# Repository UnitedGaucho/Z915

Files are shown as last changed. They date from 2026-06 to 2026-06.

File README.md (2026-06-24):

# Z915

An nRF52840 (MDBT50Q) wireless mechanical keyboard that fits in the chassis and recreates the functions of the Logitech G915. ZMK is used as the firmware.
G915 features to be recreated
  - Per-key RGB LED
  - Volume scroll wheel
  - Wireless (BLE)
  - Battery level reporting

Features to be added/upgraded
  - USB-C charging (G915 has micro-B USB)
  - Upgrade the feel of the rubber dome switches by using snap dome switches underneath the rubber
  - ZMK-included features

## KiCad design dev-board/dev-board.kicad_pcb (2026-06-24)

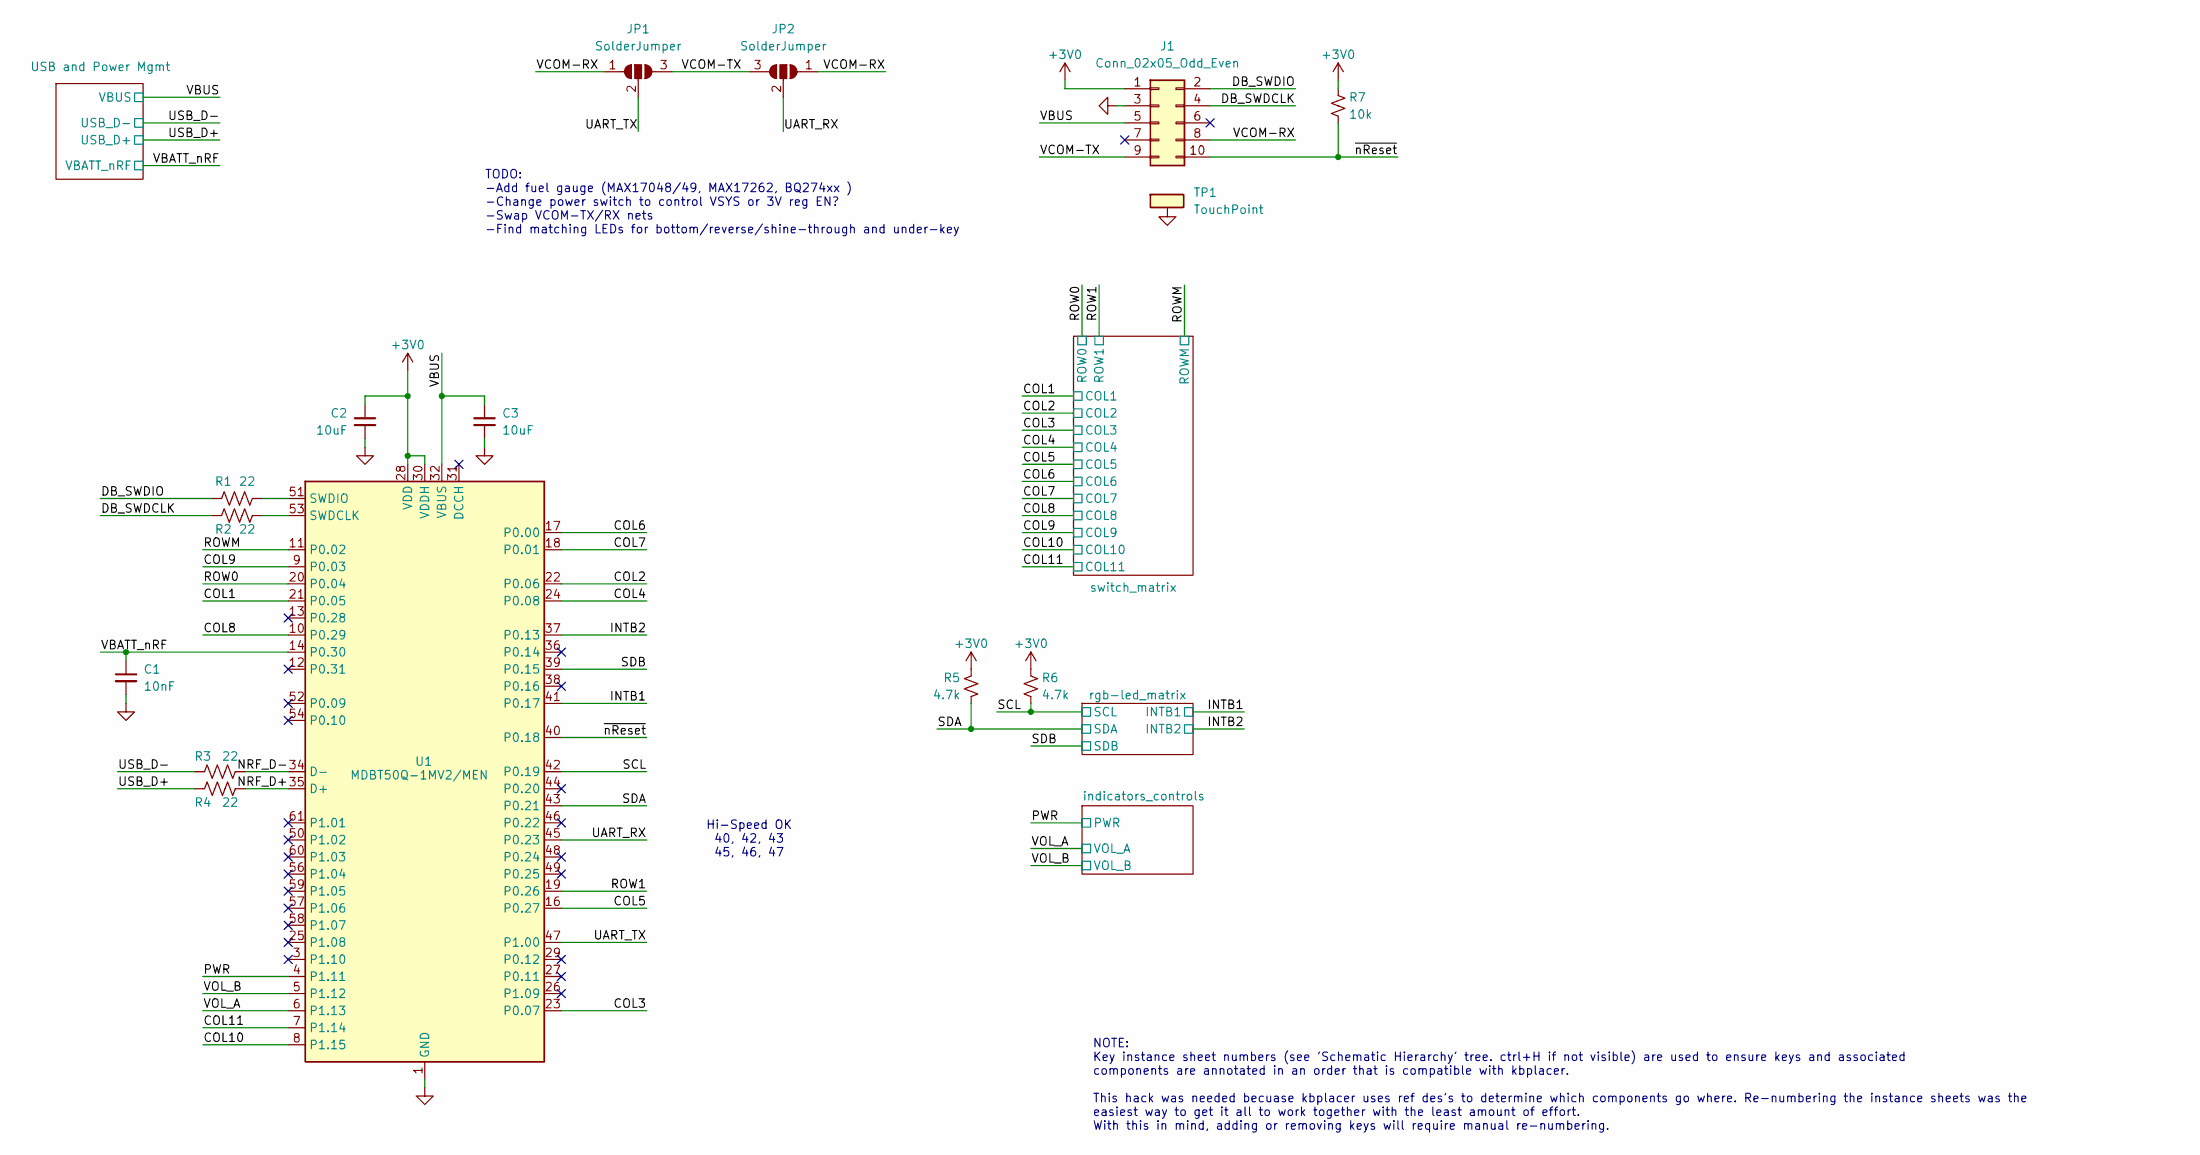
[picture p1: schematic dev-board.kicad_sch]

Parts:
C1: 10nF; C_0603_1608Metric
C2, C3: 10uF; C_1206_3216Metric
J1: Conn_02x05_Odd_Even; Tag-Connect_TC2050-IDC-FP_2x05_P1.27mm_Vertical
JP1, JP2: SolderJumper; SolderJumper-3_P1.3mm_Open_RoundedPad1.0x1.5mm
R1, R2, R3, R4: 22; R_0402_1005Metric
R5, R6: 4.7k; R_0402_1005Metric
R7: 10k; R_0402_1005Metric
TP1: TouchPoint; TestPoint_Pad_4.0x4.0mm
U1: MDBT50Q-1MV2/MEN; Raytac_MDBT50Q

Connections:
+3V0: C2.1, J1.1, R5.2, R6.2, R7.2, U1.28 (VDD), U1.30 (VDDH); also elsewhere on the board
/COL1: U1.21 (P0.05); also elsewhere on the board
/COL2: U1.22 (P0.06); also elsewhere on the board
/COL3: U1.23 (P0.07); also elsewhere on the board
/COL4: U1.24 (P0.08); also elsewhere on the board
/COL5: U1.16 (P0.27); also elsewhere on the board
/COL6: U1.17 (P0.00); also elsewhere on the board
/COL7: U1.18 (P0.01); also elsewhere on the board
/COL8: U1.10 (P0.29); also elsewhere on the board
/COL9: U1.9 (P0.03); also elsewhere on the board
/COL10: U1.8 (P1.15); also elsewhere on the board
/COL11: U1.7 (P1.14); also elsewhere on the board
/DB_SWDCLK: J1.4, R2.1
/DB_SWDIO: J1.2, R1.1
/INTB1: U1.41 (P0.17); also elsewhere on the board
/INTB2: U1.37 (P0.13); also elsewhere on the board
/NRF_D+: R4.2, U1.35 (D+)
/NRF_D-: R3.2, U1.34 (D-)
/PWR: U1.4 (P1.11); also elsewhere on the board
/ROW0: U1.20 (P0.04); also elsewhere on the board
/ROW1: U1.19 (P0.26); also elsewhere on the board
/ROWM: U1.11 (P0.02); also elsewhere on the board
/SCL: R6.1, U1.42 (P0.19); also elsewhere on the board
/SDA: R5.1, U1.43 (P0.21); also elsewhere on the board
/SDB: U1.39 (P0.15); also elsewhere on the board
/UART_RX: JP2.2 (C), U1.45 (P0.23)
/UART_TX: JP1.2 (C), U1.47 (P1.00)
/USB_D+: R4.1; also elsewhere on the board
/USB_D-: R3.1; also elsewhere on the board
/VBATT_nRF: C1.1, U1.14 (P0.30); also elsewhere on the board
/VBUS: C3.1, J1.5, U1.32 (VBUS); also elsewhere on the board
/VCOM-RX: J1.8, JP1.1 (A), JP2.1 (A)
/VCOM-TX: J1.9, JP1.3 (B), JP2.3 (B)
/VOL_A: U1.6 (P1.13); also elsewhere on the board
/VOL_B: U1.5 (P1.12); also elsewhere on the board
/~nReset: J1.10, R7.1, U1.40 (P0.18)
GND: C1.2, C2.2, C3.2, J1.3, TP1.1, U1.1 (GND), U1.2 (GND), U1.15 (GND), U1.33 (GND), U1.55 (GND); also elsewhere on the board
unnamed: R2.2, U1.53 (SWDCLK)
unnamed: R1.2, U1.51 (SWDIO)

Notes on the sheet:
NOTE: Key instance sheet numbers (see 'Schematic Hierarchy' tree. ctrl+H if not visible) are used to ensure keys and associated components are annotated in an order that is compatible with kbplacer. This hack was needed becuase kbplacer uses ref des's to determine which components go where. Re-numb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
Hi-Speed OK 40, 42, 43 45, 46, 47
TODO: -Add fuel gauge (MAX17048/49, MAX17262, BQ274xx ) -Change power switch to control VSYS or 3V reg EN? -Swap VCOM-TX/RX nets -Find matching LEDs for bottom/reverse/shine-through and under-key

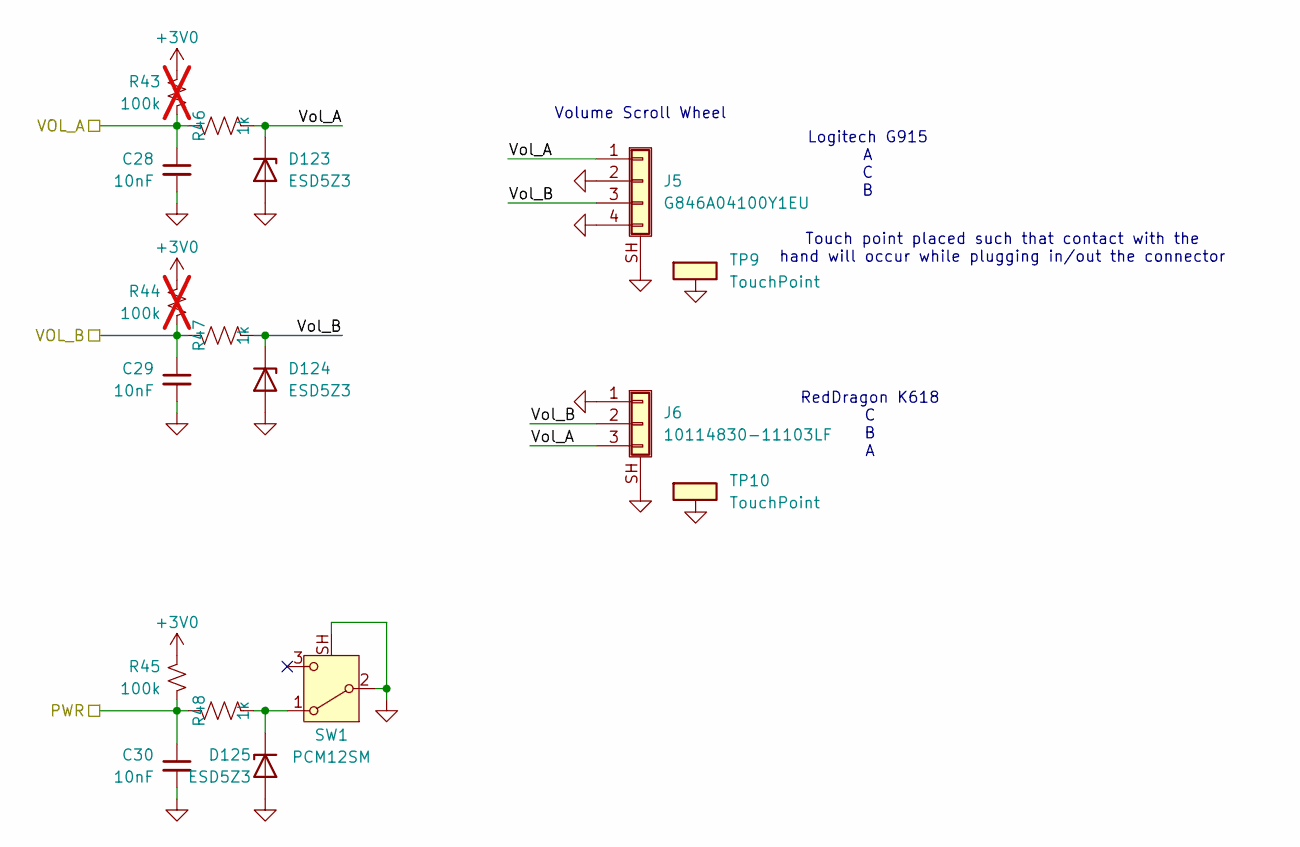
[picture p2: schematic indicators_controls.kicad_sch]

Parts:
C28, C29, C30: 10nF; C_0603_1608Metric
D123, D124, D125: ESD5Z3; D_SOD-523
J5: G846A04100Y1EU; AMPHENOL_G846A04100Y1EU
J6: 10114830-11103LF; AMPHENOL_10114830-11103LF
R43, R44: 100k; R_0402_1005Metric; not fitted
R45: 100k; R_0402_1005Metric
R46, R47, R48: 1k; R_0402_1005Metric
SW1: PCM12SM; SW_PCM12SMTR
TP9, TP10: TouchPoint; TestPoint_Pad_4.0x4.0mm

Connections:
+3V0: R43.2, R44.2, R45.2; also elsewhere on the board
/PWR: C30.1, R45.1, R48.1; also elsewhere on the board
/VOL_A: C28.1, R43.1, R46.1; also elsewhere on the board
/VOL_B: C29.1, R44.1, R47.1; also elsewhere on the board
/indicators_controls/Vol_A: D123.1 (K), J5.1, J6.3, R46.2
/indicators_controls/Vol_B: D124.1 (K), J5.3, J6.2, R47.2
GND: C28.2, C29.2, C30.2, D123.2 (A), D124.2 (A), D125.2 (A), J5.2, J5.4, J5.SH (Shield), J6.1, J6.SH (Shield), SW1.2 (B), SW1.SH, TP9.1, TP10.1; also elsewhere on the board
unnamed: D125.1 (K), R48.2, SW1.1 (A)

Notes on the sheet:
Logitech G915 A C B
Touch point placed such that contact with the hand will occur while plugging in/out the connector
RedDragon K618 C B A
Volume Scroll Wheel

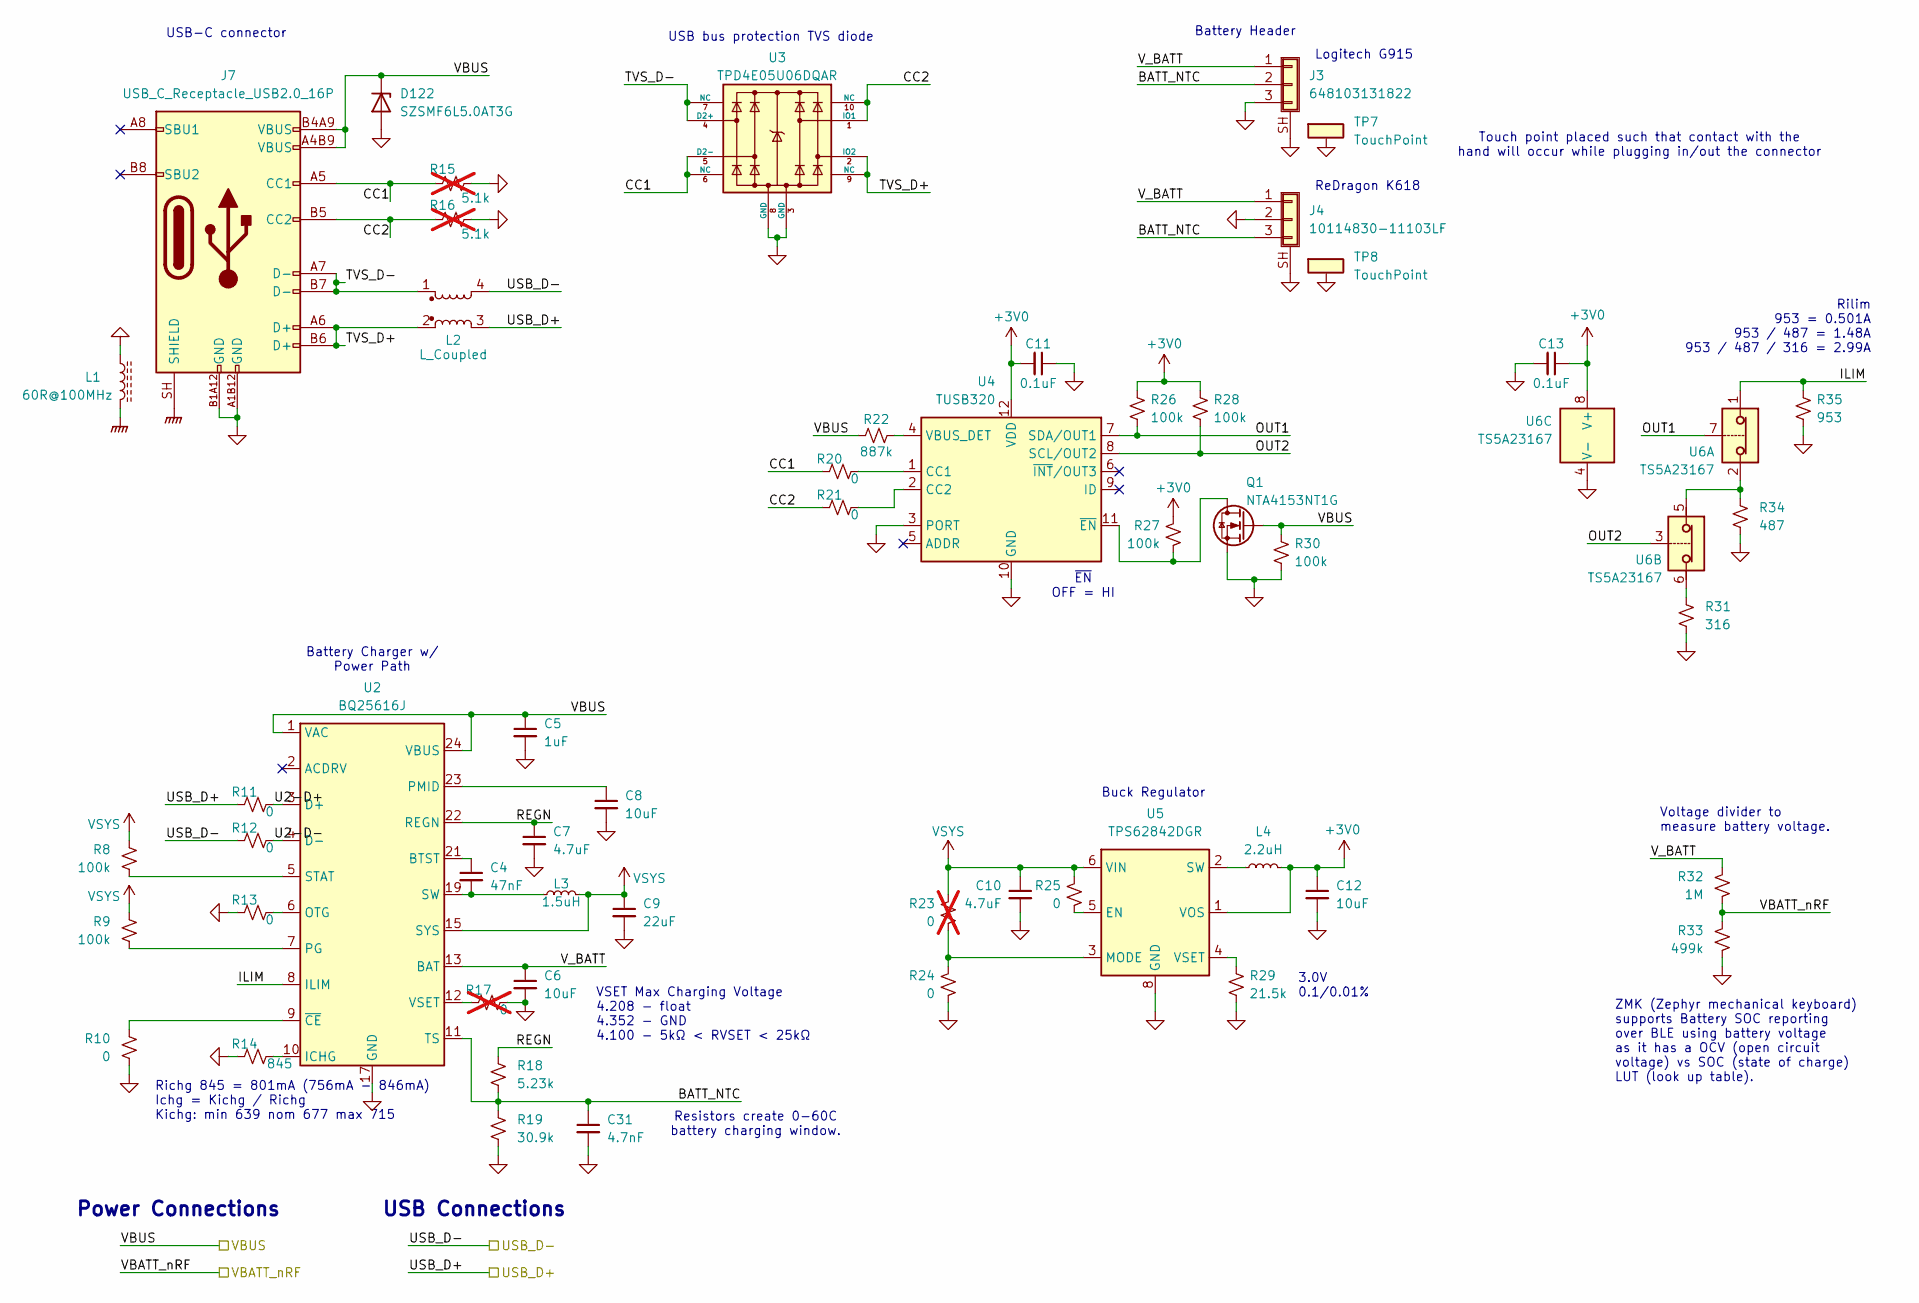
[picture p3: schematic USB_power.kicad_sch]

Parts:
C4: 47nF; C_0402_1005Metric
C5: 1uF; C_0603_1608Metric
C6, C8: 10uF; C_0805_2012Metric
C7: 4.7uF; C_0402_1005Metric
C9: 22uF; C_0805_2012Metric
C10: 4.7uF; C_0805_2012Metric
C11, C13: 0.1uF; C_0402_1005Metric
C12: 10uF; C_0402_1005Metric
C31: 4.7nF; C_0402_1005Metric
D122: SZSMF6L5.0AT3G; D_SOD-123F
J3: 648103131822
J4: 10114830-11103LF; AMPHENOL_10114830-11103LF
J7: USB_C_Receptacle_USB2.0_16P; AMPHENOL_12402012E212A
L1: 60R@100MHz; L_0603_1608Metric
L2: L_Coupled; FIL_ACM2012-900-2P-T001
L3: 1.5uH; L_1008_2520Metric
L4: 2.2uH; L_Murata_DFE201610P
Q1: NTA4153NT1G; SOT-416
R8, R9, R26, R27, R28, R30: 100k; R_0402_1005Metric
R10, R11, R12, R13, R20, R21, R24, R25: 0; R_0402_1005Metric
R14: 845; R_0402_1005Metric
R15, R16: 5.1k; R_0402_1005Metric; not fitted
R17, R23: 0; R_0402_1005Metric; not fitted
R18: 5.23k; R_0402_1005Metric
R19: 30.9k; R_0402_1005Metric
R22: 887k; R_0402_1005Metric
R29: 21.5k; R_0402_1005Metric
R31: 316; R_0402_1005Metric
R32: 1M; R_0402_1005Metric
R33: 499k; R_0402_1005Metric
R34: 487; R_0402_1005Metric
R35: 953; R_0402_1005Metric
TP7, TP8: TouchPoint; TestPoint_Pad_4.0x4.0mm
U2: BQ25616J; Texas_RTW_WQFN-24-1EP_4x4mm_P0.5mm_EP2.7x2.7mm_ThermalVias
U3: TPD4E05U06DQAR; USON-10
U4: TUSB320; Texas_X2QFN-12_1.6x1.6mm_P0.4mm
U5: TPS62842DGR; HVSSOP-8-1EP_3x3mm_P0.65mm_EP1.57x1.89mm
U6: TS5A23167; VSSOP-8_2.3x2mm_P0.5mm

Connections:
+3V0: C11.2, C12.1, C13.1, L4.2, R26.2, R27.2, R28.2, U4.12 (VDD), U5.1 (VOS), U6.8 (V+); also elsewhere on the board
/USB and Power Mgmt/BATT_NTC: C31.1, J3.2, J4.3, R18.1, R19.2, U2.11 (TS)
/USB and Power Mgmt/CC1: J7.A5 (CC1), R15.2, R20.2, U3.5 (D2-), U3.6 (NC)
/USB and Power Mgmt/CC2: J7.B5 (CC2), R16.2, R21.2, U3.1 (IO1), U3.10 (NC)
/USB and Power Mgmt/ILIM: R35.2, U2.8 (ILIM), U6.1
/USB and Power Mgmt/OUT1: R26.1, U4.7 (SDA/OUT1), U6.7
/USB and Power Mgmt/OUT2: R28.1, U4.8 (SCL/OUT2), U6.3
/USB and Power Mgmt/REGN: C7.1, R18.2, U2.22 (REGN)
/USB and Power Mgmt/TVS_D+: J7.A6 (D+), J7.B6 (D+), L2.2, U3.2 (IO2), U3.9 (NC)
/USB and Power Mgmt/TVS_D-: J7.A7 (D-), J7.B7 (D-), L2.1, U3.4 (D2+), U3.7 (NC)
/USB and Power Mgmt/U2-D+: R11.1, U2.3 (D+)
/USB and Power Mgmt/U2-D-: R12.1, U2.4 (D-)
/USB_D+: L2.3, R11.2; also elsewhere on the board
/USB_D-: L2.4, R12.2; also elsewhere on the board
/VBATT_nRF: R32.1, R33.2; also elsewhere on the board
/VBUS: C5.1, D122.1 (K), J7.A4B9 (VBUS), J7.B4A9 (VBUS), Q1.G, R22.2, R30.2, U2.1 (VAC), U2.24 (VBUS); also elsewhere on the board
BAT: C6.1, J3.1, J4.1, R32.2, U2.13 (BAT), U2.14 (BAT)
GND: C5.2, C6.2, C7.2, C8.2, C9.2, C10.2, C11.1, C12.2, C13.2, C31.2, D122.2 (A), J3.3, J3.SH (Shield), J4.2, J4.SH (Shield), J7.A1B12 (GND), J7.B1A12 (GND), L1.1, Q1.S, R10.2, R13.2, R14.2, R15.1, R16.1, R17.1, R19.1, R24.1, R29.1, R30.1, R31.1, R33.1, R34.1, R35.1, TP7.1, TP8.1, U2.17 (GND), U2.18 (GND), U2.25 (GND), U3.3 (GND), U3.8 (GND), U4.3 (PORT), U4.10 (GND), U5.8 (GND), U5.9 (EP), U6.4 (V-); also elsewhere on the board
GNDPWR: J7.SH (SHIELD), L1.2
unnamed: C4.2, L3.1, U2.19 (SW), U2.20 (SW)
unnamed: R31.2, U6.6
unnamed: R34.2, U6.2, U6.5
unnamed: C4.1, U2.21 (BTST)
unnamed: R14.1, U2.10 (ICHG)
unnamed: R13.1, U2.6 (OTG)
unnamed: R9.2, U2.7 (PG)
unnamed: C8.1, U2.23 (PMID)
unnamed: R8.2, U2.5 (STAT)
unnamed: R17.2, U2.12 (VSET)
unnamed: R10.1, U2.9 (~CE)
unnamed: R20.1, U4.1 (CC1)
unnamed: R21.1, U4.2 (CC2)
unnamed: R22.1, U4.4 (VBUS_DET)
unnamed: Q1.D, R27.1, U4.11 (~EN)
unnamed: R25.1, U5.5 (EN)
unnamed: R23.1, R24.2, U5.3 (MODE)
unnamed: L4.1, U5.2 (SW)
unnamed: R29.2, U5.4 (VSET)
VSYS: C9.1, C10.1, L3.2, R8.1, R9.1, R23.2, R25.2, U2.15 (SYS), U2.16 (SYS), U5.6 (VIN); also elsewhere on the board

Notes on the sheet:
ReDragon K618
Resistors create 0-60C battery charging window.
Voltage divider to measure battery voltage.
Touch point placed such that contact with the hand will occur while plugging in/out the connector
Battery Charger w/ Power Path
USB bus protection TVS diode
Richg 845 = 801mA (756mA - 846mA) Ichg = Kichg / Richg Kichg: min 639 nom 677 max 715
3.0V 0.1/0.01%
USB Connections
Buck Regulator
USB-C connector
Logitech G915
ZMK (Zephyr mechanical keyboard) supports Battery SOC reporting over BLE using battery voltage as it has a OCV (open circuit voltage) vs SOC (state of charge) LUT (look up table).
Rilim 953 = 0.501A 953 / 487 = 1.48A 953 / 487 / 316 = 2.99A
VSET Max Charging Voltage 4.208 - float 4.352 - GND 4.100 - 5kΩ < RVSET < 25kΩ
Battery Header
Power Connections
~{EN} OFF = HI

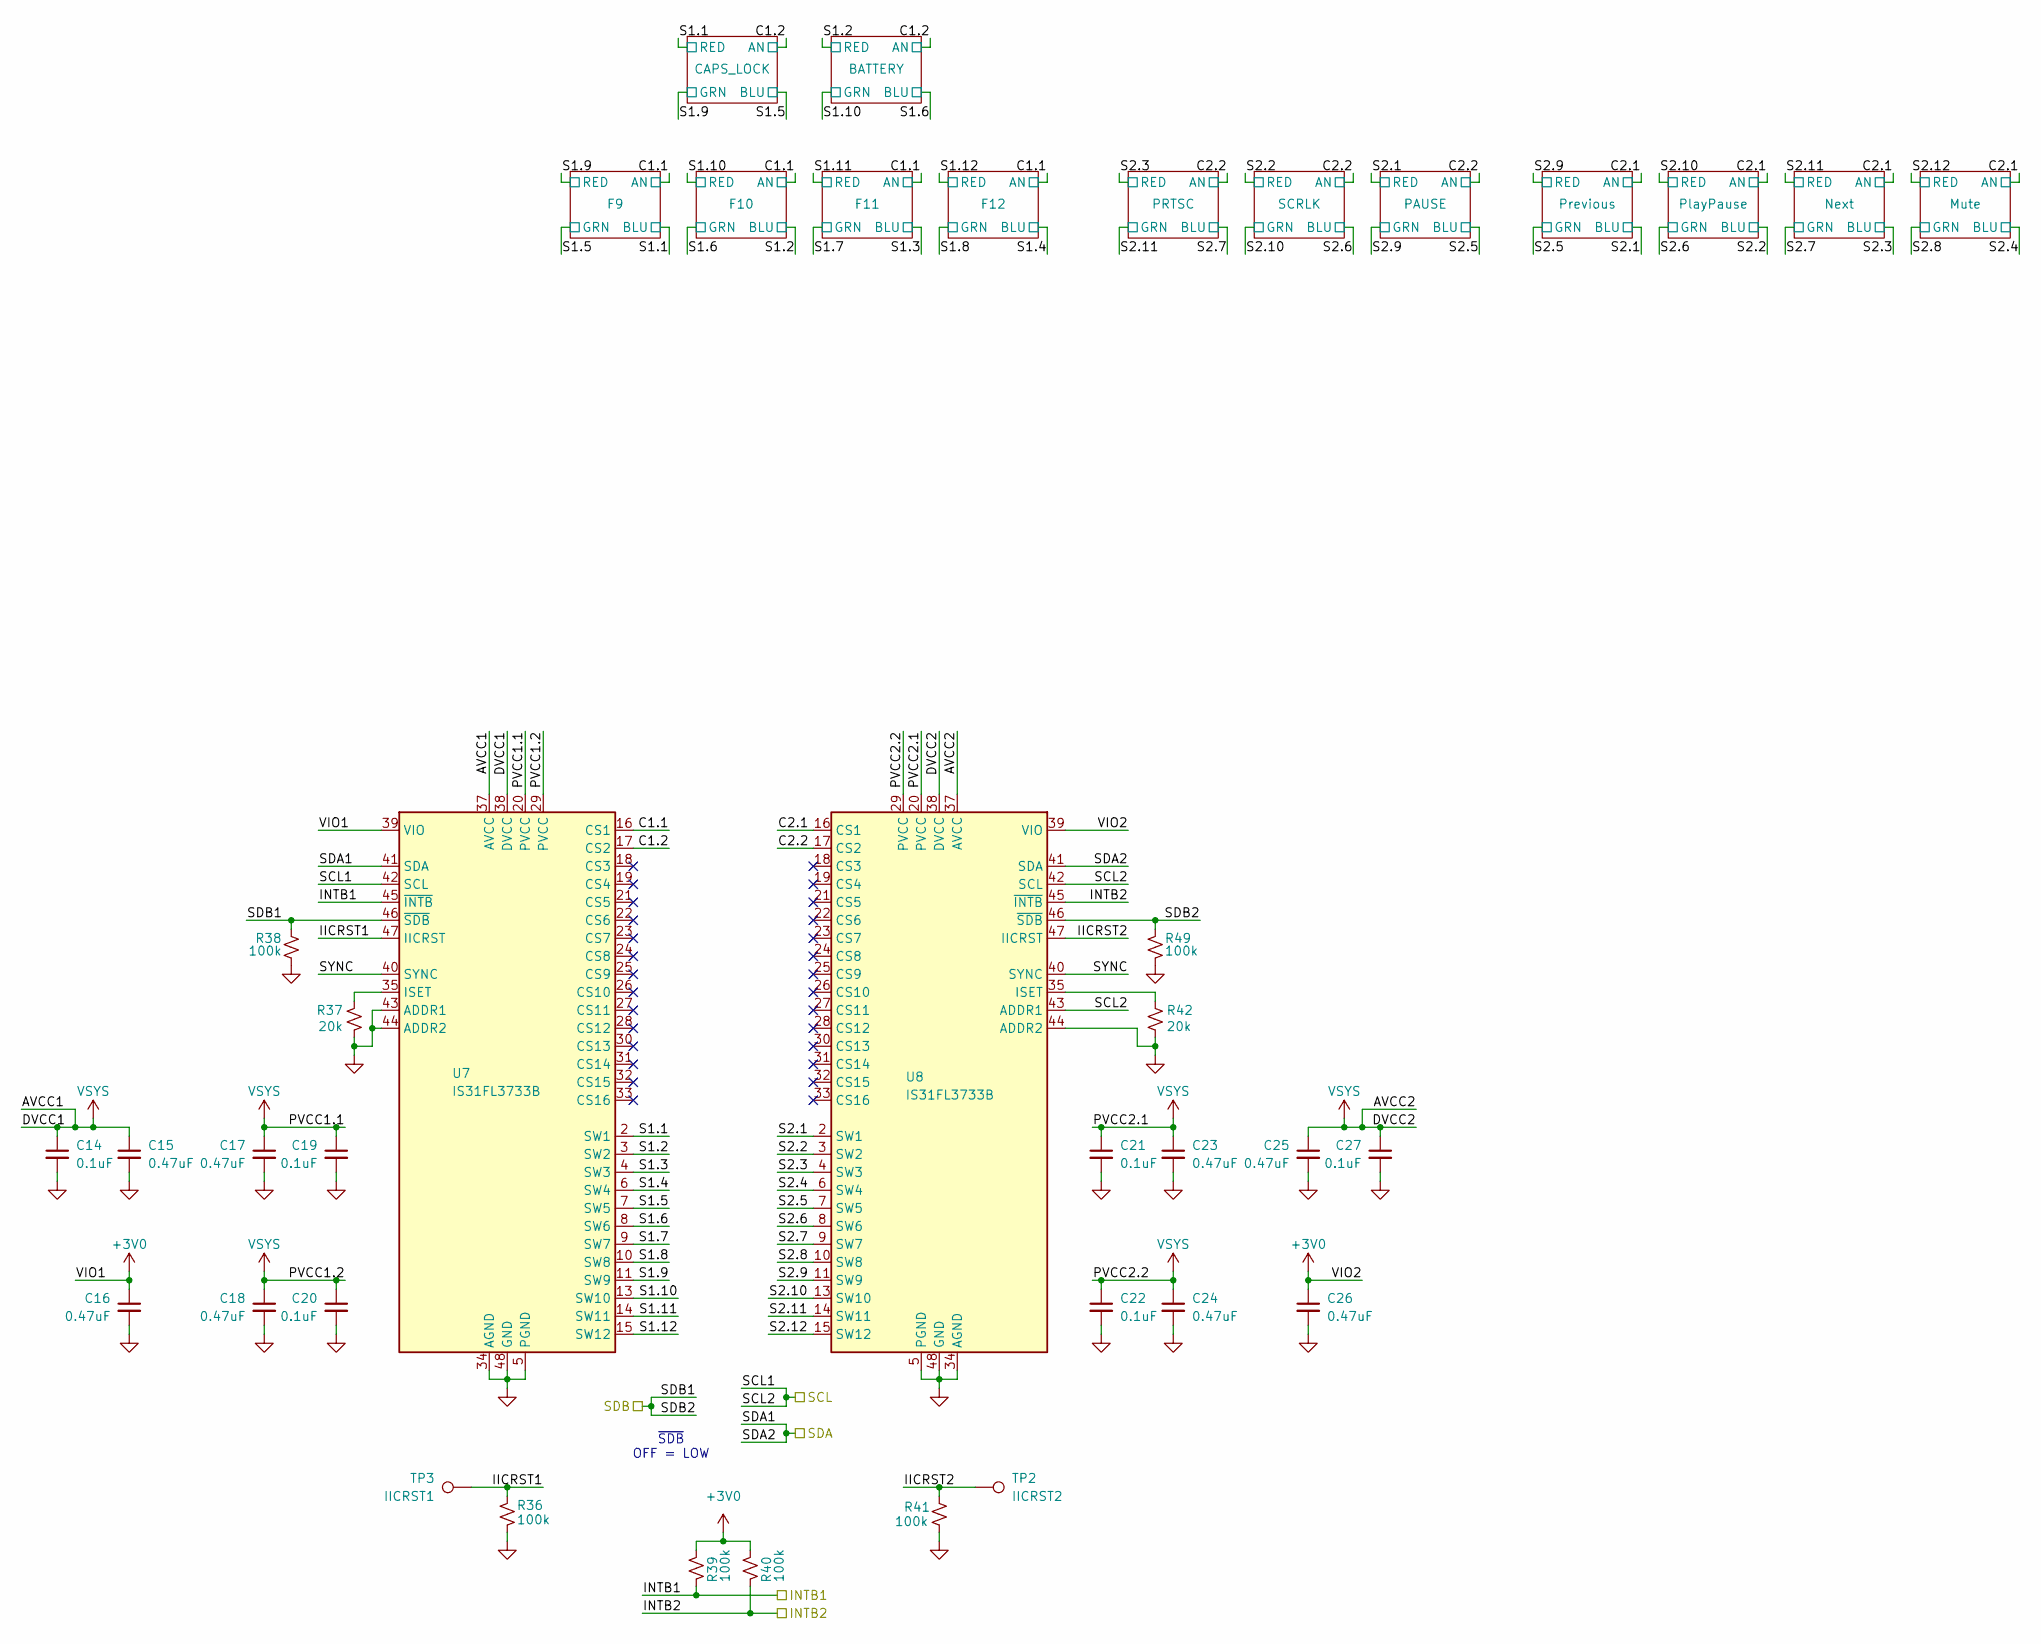
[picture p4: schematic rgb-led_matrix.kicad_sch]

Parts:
C14, C19, C20, C21, C22, C27: 0.1uF; C_0402_1005Metric
C15, C16, C17, C18, C23, C24, C25, C26: 0.47uF; C_0402_1005Metric
R36, R38, R39, R40, R41, R49: 100k; R_0402_1005Metric
R37, R42: 20k; R_0402_1005Metric
TP2: IICRST2; TestPoint_Pad_D1.0mm
TP3: IICRST1; TestPoint_Pad_D1.0mm
U7, U8: IS31FL3733B; TQFP-48-1EP_7x7mm_P0.5mm_EP5x5mm

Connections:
+3V0: C16.1, C26.1, R39.2, R40.2, U7.39 (VIO), U8.39 (VIO); also elsewhere on the board
/INTB1: R39.1, U7.45 (~INTB); also elsewhere on the board
/INTB2: R40.1, U8.45 (~INTB); also elsewhere on the board
/SCL: U7.42 (SCL), U8.42 (SCL), U8.43 (ADDR1); also elsewhere on the board
/SDA: U7.41 (SDA), U8.41 (SDA); also elsewhere on the board
/SDB: R38.2, R49.2, U7.46 (~SDB), U8.46 (~SDB); also elsewhere on the board
/rgb-led_matrix/C1.1: U7.16 (CS1); also elsewhere on the board
/rgb-led_matrix/C1.2: U7.17 (CS2); also elsewhere on the board
/rgb-led_matrix/C2.1: U8.16 (CS1); also elsewhere on the board
/rgb-led_matrix/C2.2: U8.17 (CS2); also elsewhere on the board
/rgb-led_matrix/IICRST1: R36.2, TP3.1 (1_1), U7.47 (IICRST)
/rgb-led_matrix/IICRST2: R41.1, TP2.1 (1_1), U8.47 (IICRST)
/rgb-led_matrix/S1.1: U7.2 (SW1); also elsewhere on the board
/rgb-led_matrix/S1.2: U7.3 (SW2); also elsewhere on the board
/rgb-led_matrix/S1.3: U7.4 (SW3); also elsewhere on the board
/rgb-led_matrix/S1.4: U7.6 (SW4); also elsewhere on the board
/rgb-led_matrix/S1.5: U7.7 (SW5); also elsewhere on the board
/rgb-led_matrix/S1.6: U7.8 (SW6); also elsewhere on the board
/rgb-led_matrix/S1.7: U7.9 (SW7); also elsewhere on the board
/rgb-led_matrix/S1.8: U7.10 (SW8); also elsewhere on the board
/rgb-led_matrix/S1.9: U7.11 (SW9); also elsewhere on the board
/rgb-led_matrix/S1.10: U7.13 (SW10); also elsewhere on the board
/rgb-led_matrix/S1.11: U7.14 (SW11); also elsewhere on the board
/rgb-led_matrix/S1.12: U7.15 (SW12); also elsewhere on the board
/rgb-led_matrix/S2.1: U8.2 (SW1); also elsewhere on the board
/rgb-led_matrix/S2.2: U8.3 (SW2); also elsewhere on the board
/rgb-led_matrix/S2.3: U8.4 (SW3); also elsewhere on the board
/rgb-led_matrix/S2.4: U8.6 (SW4); also elsewhere on the board
/rgb-led_matrix/S2.5: U8.7 (SW5); also elsewhere on the board
/rgb-led_matrix/S2.6: U8.8 (SW6); also elsewhere on the board
/rgb-led_matrix/S2.7: U8.9 (SW7); also elsewhere on the board
/rgb-led_matrix/S2.8: U8.10 (SW8); also elsewhere on the board
/rgb-led_matrix/S2.9: U8.11 (SW9); also elsewhere on the board
/rgb-led_matrix/S2.10: U8.13 (SW10); also elsewhere on the board
/rgb-led_matrix/S2.11: U8.14 (SW11); also elsewhere on the board
/rgb-led_matrix/S2.12: U8.15 (SW12); also elsewhere on the board
/rgb-led_matrix/SYNC: U7.40 (SYNC), U8.40 (SYNC)
GND: C14.2, C15.2, C16.2, C17.2, C18.2, C19.2, C20.2, C21.2, C22.2, C23.2, C24.2, C25.2, C26.2, C27.2, R36.1, R37.2, R38.1, R41.2, R42.2, R49.1, U7.5 (PGND), U7.12 (PGND), U7.34 (AGND), U7.43 (ADDR1), U7.44 (ADDR2), U7.48 (GND), U7.49 (GND), U8.5 (PGND), U8.12 (PGND), U8.34 (AGND), U8.44 (ADDR2), U8.48 (GND), U8.49 (GND); also elsewhere on the board
unnamed: R37.1, U7.35 (ISET)
unnamed: R42.1, U8.35 (ISET)
VSYS: C14.1, C15.1, C17.1, C18.1, C19.1, C20.1, C21.1, C22.1, C23.1, C24.1, C25.1, C27.1, U7.20 (PVCC), U7.29 (PVCC), U7.37 (AVCC), U7.38 (DVCC), U8.20 (PVCC), U8.29 (PVCC), U8.37 (AVCC), U8.38 (DVCC); also elsewhere on the board

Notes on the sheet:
~{SDB} OFF = LOW

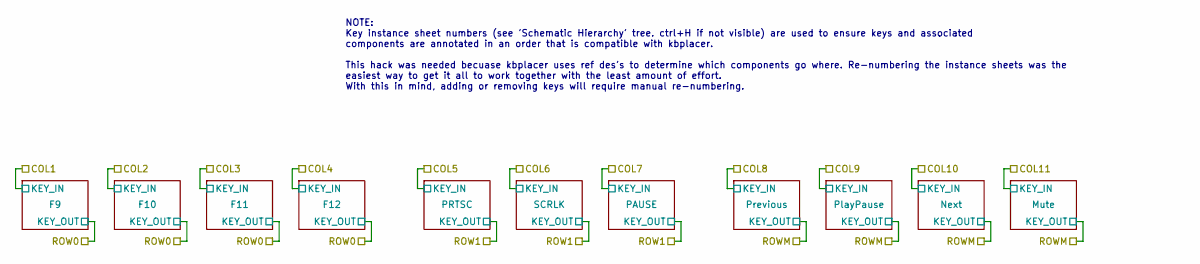
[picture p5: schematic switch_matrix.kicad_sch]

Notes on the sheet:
NOTE: Key instance sheet numbers (see 'Schematic Hierarchy' tree. ctrl+H if not visible) are used to ensure keys and associated components are annotated in an order that is compatible with kbplacer. This hack was needed becuase kbplacer uses ref des's to determine which components go where. Re-numb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

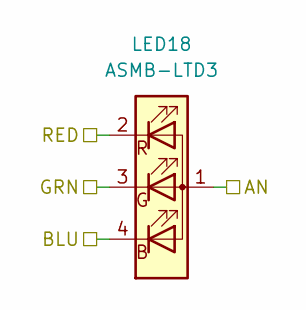
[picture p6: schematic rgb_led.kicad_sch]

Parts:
LED18: ASMB-LTD3; LED_ASMB-LTD3

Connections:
/rgb-led_matrix/C1.1: LED18.1 (A); also elsewhere on the board
/rgb-led_matrix/S1.1: LED18.4 (BK); also elsewhere on the board
/rgb-led_matrix/S1.5: LED18.3 (GK); also elsewhere on the board
/rgb-led_matrix/S1.9: LED18.2 (RK); also elsewhere on the board

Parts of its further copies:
LED19, LED20, LED21, LED22, LED23, LED24, LED122, LED123: ASMB-LTD3; LED_ASMB-LTD3

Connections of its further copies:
/rgb-led_matrix/C1.1: LED19.1 (A), LED20.1 (A), LED21.1 (A); also elsewhere on the board
/rgb-led_matrix/C1.2: LED122.1 (A), LED123.1 (A); also elsewhere on the board
/rgb-led_matrix/C2.2: LED22.1 (A), LED23.1 (A), LED24.1 (A); also elsewhere on the board
/rgb-led_matrix/S1.1: LED122.2 (RK); also elsewhere on the board
/rgb-led_matrix/S1.2: LED19.4 (BK), LED123.2 (RK); also elsewhere on the board
/rgb-led_matrix/S1.3: LED20.4 (BK); also elsewhere on the board
/rgb-led_matrix/S1.4: LED21.4 (BK); also elsewhere on the board
/rgb-led_matrix/S1.5: LED122.4 (BK); also elsewhere on the board
/rgb-led_matrix/S1.6: LED19.3 (GK), LED123.4 (BK); also elsewhere on the board
/rgb-led_matrix/S1.7: LED20.3 (GK); also elsewhere on the board
/rgb-led_matrix/S1.8: LED21.3 (GK); also elsewhere on the board
/rgb-led_matrix/S1.9: LED122.3 (GK); also elsewhere on the board
/rgb-led_matrix/S1.10: LED19.2 (RK), LED123.3 (GK); also elsewhere on the board
/rgb-led_matrix/S1.11: LED20.2 (RK); also elsewhere on the board
/rgb-led_matrix/S1.12: LED21.2 (RK); also elsewhere on the board
/rgb-led_matrix/S2.1: LED24.2 (RK); also elsewhere on the board
/rgb-led_matrix/S2.2: LED23.2 (RK); also elsewhere on the board
/rgb-led_matrix/S2.3: LED22.2 (RK); also elsewhere on the board
/rgb-led_matrix/S2.5: LED24.4 (BK); also elsewhere on the board
/rgb-led_matrix/S2.6: LED23.4 (BK); also elsewhere on the board
/rgb-led_matrix/S2.7: LED22.4 (BK); also elsewhere on the board
/rgb-led_matrix/S2.9: LED24.3 (GK); also elsewhere on the board
/rgb-led_matrix/S2.10: LED23.3 (GK); also elsewhere on the board
/rgb-led_matrix/S2.11: LED22.3 (GK); also elsewhere on the board

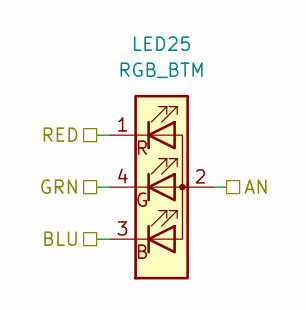
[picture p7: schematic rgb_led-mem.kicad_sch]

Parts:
LED25: RGB_BTM; LED_XZMDKCBDDG45S-9

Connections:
/rgb-led_matrix/C2.1: LED25.2 (A); also elsewhere on the board
/rgb-led_matrix/S2.1: LED25.3 (BK); also elsewhere on the board
/rgb-led_matrix/S2.5: LED25.4 (GK); also elsewhere on the board
/rgb-led_matrix/S2.9: LED25.1 (RK); also elsewhere on the board

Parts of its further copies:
LED26: RGB_BTM; LED_XZMDKCBDDG45S-9

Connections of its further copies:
/rgb-led_matrix/C2.1: LED26.2 (A); also elsewhere on the board
/rgb-led_matrix/S2.2: LED26.3 (BK); also elsewhere on the board
/rgb-led_matrix/S2.6: LED26.4 (GK); also elsewhere on the board
/rgb-led_matrix/S2.10: LED26.1 (RK); also elsewhere on the board

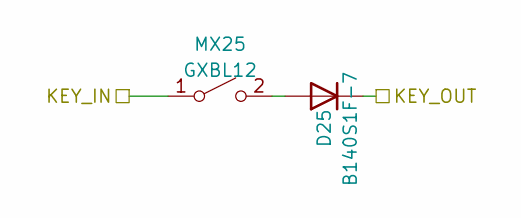
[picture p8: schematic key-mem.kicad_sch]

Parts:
D25: B140S1F-7; D_SOD-123F
MX25: GXBL12; SW_GXBL12450

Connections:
/COL8: MX25.1 (A); also elsewhere on the board
/ROWM: D25.1 (K); also elsewhere on the board
unnamed: D25.2 (A), MX25.2 (B)

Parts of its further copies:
D26, D27, D28: B140S1F-7; D_SOD-123F
MX26, MX27, MX28: GXBL12; SW_GXBL12450

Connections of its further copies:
/COL9: MX26.1 (A); also elsewhere on the board
/COL10: MX27.1 (A); also elsewhere on the board
/COL11: MX28.1 (A); also elsewhere on the board
/ROWM: D26.1 (K), D27.1 (K), D28.1 (K); also elsewhere on the board
unnamed: D26.2 (A), MX26.2 (B)
unnamed: D27.2 (A), MX27.2 (B)
unnamed: D28.2 (A), MX28.2 (B)

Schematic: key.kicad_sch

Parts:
D18: B140S1F-7; D_SOD-123F
MX18: 1.00u; SW_Kailh_Choc_V1_THT

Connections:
/COL1: MX18.2 (B); also elsewhere on the board
/ROW0: D18.1 (K); also elsewhere on the board
unnamed: D18.2 (A), MX18.1 (A)

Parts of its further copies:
D19, D20, D21, D22, D23, D24: B140S1F-7; D_SOD-123F
MX19, MX20, MX21, MX22, MX23, MX24: 1.00u; SW_Kailh_Choc_V1_THT

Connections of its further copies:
/COL2: MX19.2 (B); also elsewhere on the board
/COL3: MX20.2 (B); also elsewhere on the board
/COL4: MX21.2 (B); also elsewhere on the board
/COL5: MX22.2 (B); also elsewhere on the board
/COL6: MX23.2 (B); also elsewhere on the board
/COL7: MX24.2 (B); also elsewhere on the board
/ROW0: D19.1 (K), D20.1 (K), D21.1 (K); also elsewhere on the board
/ROW1: D22.1 (K), D23.1 (K), D24.1 (K); also elsewhere on the board
unnamed: D19.2 (A), MX19.1 (A)
unnamed: D20.2 (A), MX20.1 (A)
unnamed: D21.2 (A), MX21.1 (A)
unnamed: D22.2 (A), MX22.1 (A)
unnamed: D23.2 (A), MX23.1 (A)
unnamed: D24.2 (A), MX24.1 (A)

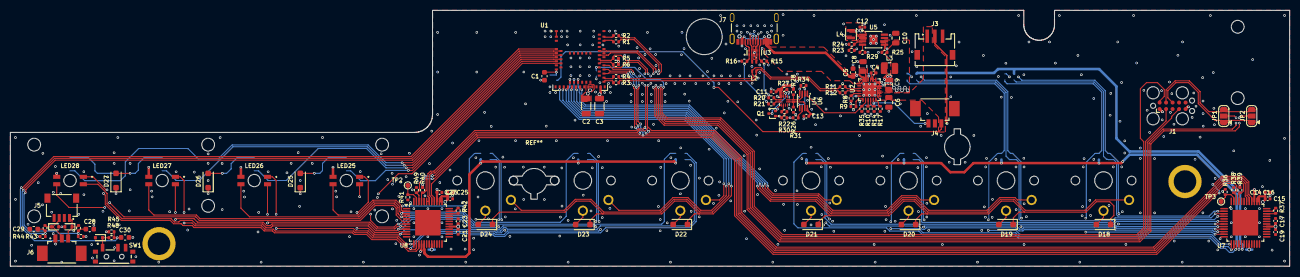
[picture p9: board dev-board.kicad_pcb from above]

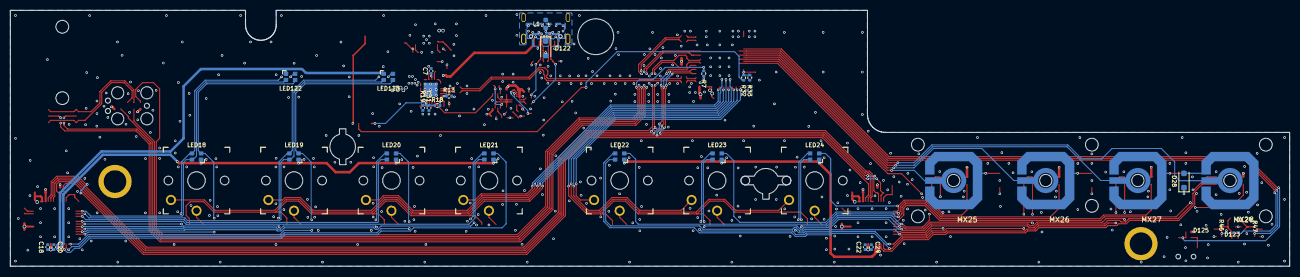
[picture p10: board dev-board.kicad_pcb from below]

Board: 4 copper layers, 250.0 x 50.0 mm, 143 parts (35 on the bottom side), 119 nets.

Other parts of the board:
LED27, LED28: RGB_BTM; LED_XZMDKCBDDG45S-9

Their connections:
/rgb-led_matrix/C2.1: LED27.2 (A), LED28.2 (A); also elsewhere on the board
/rgb-led_matrix/S2.3: LED27.3 (BK); also elsewhere on the board
/rgb-led_matrix/S2.4: LED28.3 (BK); also elsewhere on the board
/rgb-led_matrix/S2.7: LED27.4 (GK); also elsewhere on the board
/rgb-led_matrix/S2.8: LED28.4 (GK); also elsewhere on the board
/rgb-led_matrix/S2.11: LED27.1 (RK); also elsewhere on the board
/rgb-led_matrix/S2.12: LED28.1 (RK); also elsewhere on the board

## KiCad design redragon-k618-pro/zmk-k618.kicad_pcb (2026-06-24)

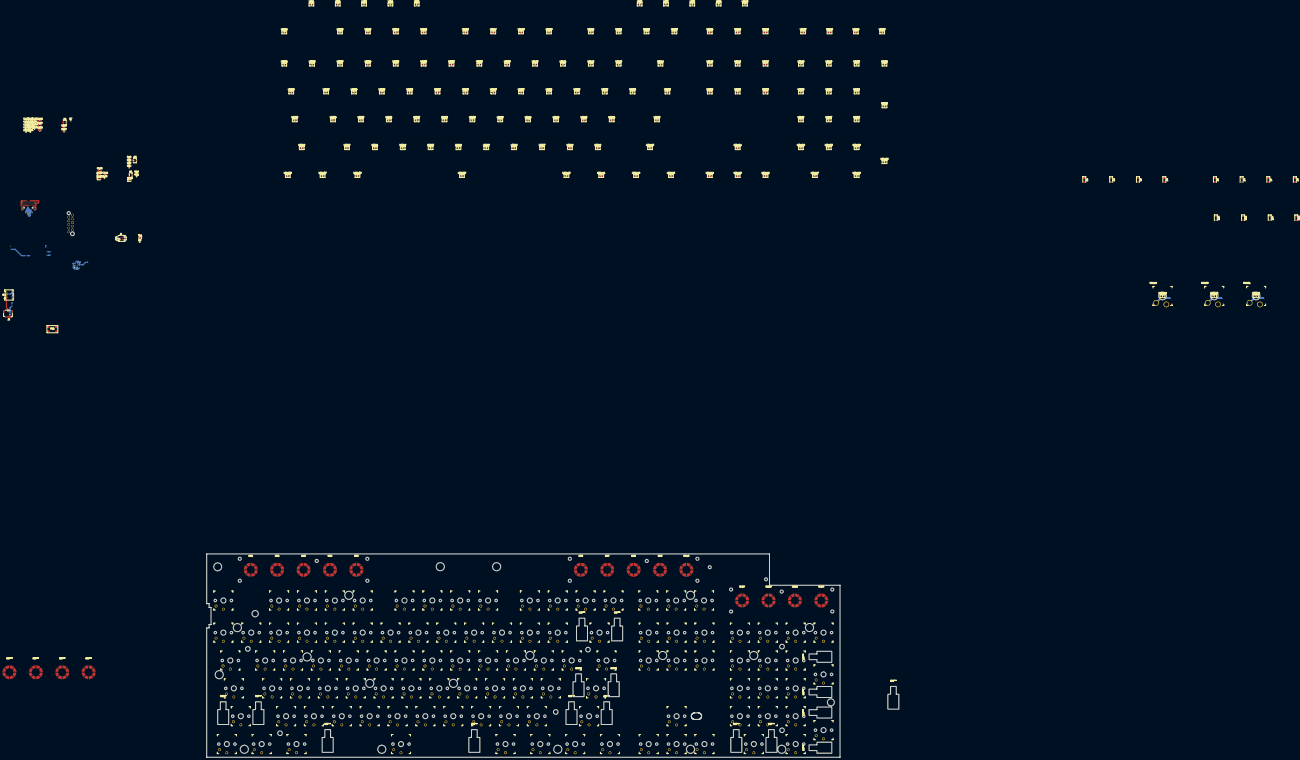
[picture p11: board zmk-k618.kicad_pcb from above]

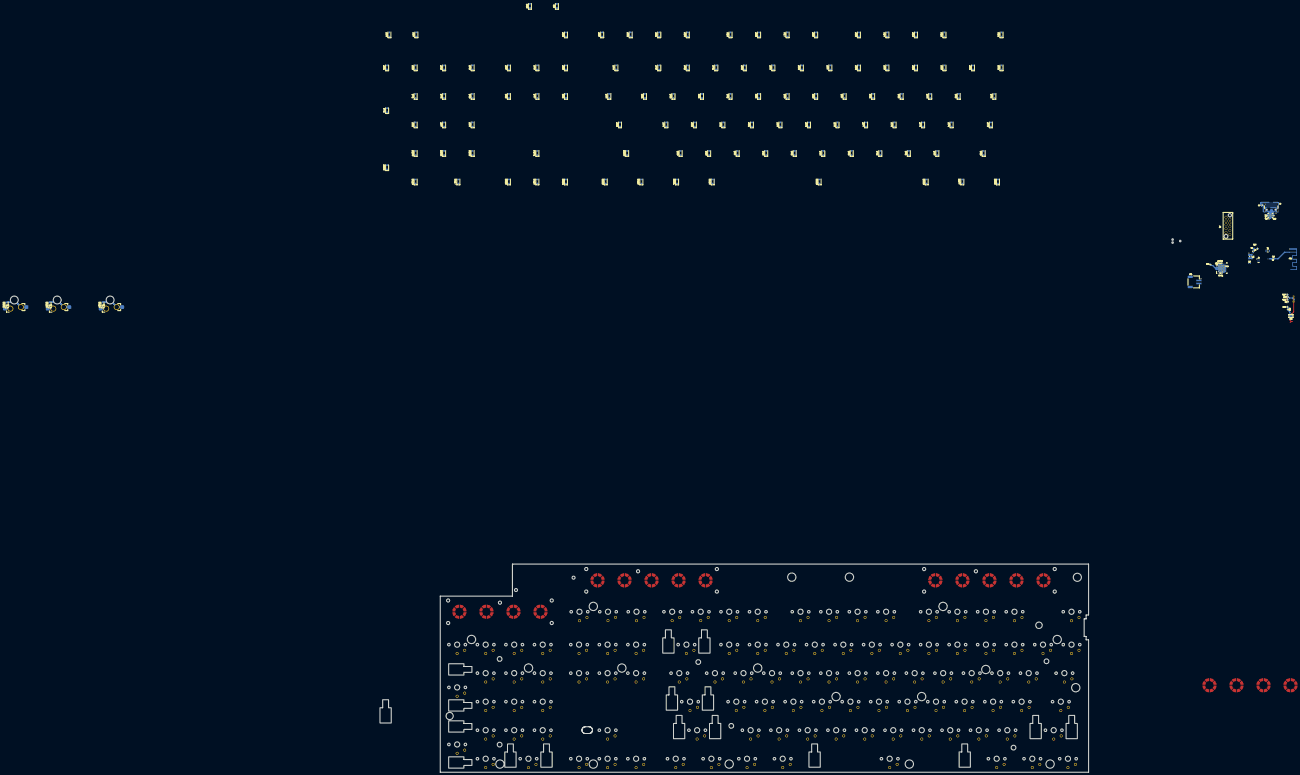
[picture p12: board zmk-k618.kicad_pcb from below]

Board: 2 copper layers, 472.0 x 138.7 mm, 560 parts (141 on the bottom side), 232 nets.

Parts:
AE1: Antenna_Shield; BLE_ANTENNA
BT1: Lipo cell; JST-2-pin
C1, C16, C18, C21: 4u7F; C_0402_1005Metric
C2, C3, C8, C9, C123, C124, C129, C130: 8pF; C_0402_1005Metric
C4, C6, C20: 1uF; C_0402_1005Metric
C5, C7, C10, C14, C15, C22, C23, C24, C25, C26, C27, C28, C29, C30, C31, C32, C33, C34, C35, C36, C37, C38, C39, C40, C41, C42, C43, C44, C45, C46, C47, C48, C49, C50, C51, C52, C53, C54, C55, C56, C57, C58, C59, C60, C61, C62, C63, C64, C65, C66, C67, C68, C69, C70, C71, C72, C73, C74, C75, C76, C77, C78, C79, C80, C81, C82, C83, C84, C85, C86, C87, C88, C89, C90, C91, C92, C93, C94, C95, C96, C97, C98, C99, C100, C101, C102, C103, C104, C105, C106, C107, C108, C109, C110, C111, C112, C113, C114, C115, C116, C117, C118, C119, C120, C121, C126, C128, C131, C135, C136, C143: 100nF; C_0402_1005Metric
C11, C132: 820pF; C_0402_1005Metric
C12, C133: 100pF; C_0402_1005Metric
C13, C134: DNP; C_0402_1005Metric
C17, C138: 1pF; C_0402_1005Metric
C19, C140: 1.2pF; C_0402_1005Metric
C122, C137, C139, C142: 4u7F; C_0805_2012Metric
C125, C127, C141: 1uF; C_0603_1608Metric
D1, D2, D3, D4, D5, D6, D7, D8, D9, D10, D11, D12, D13, D14, D15, D16, D17, D18, D19, D20, D21, D22, D23, D24, D25, D26, D27, D28, D29, D30, D31, D32, D33, D34, D35, D36, D37, D38, D39, D40, D41, D42, D43, D44, D45, D46, D47, D48, D49, D50, D51, D52, D53, D54, D55, D56, D57, D58, D59, D60, D61, D62, D63, D64, D65, D66, D67, D68, D69, D70, D71, D72, D73, D74, D75, D76, D77, D78, D79, D80, D81, D82, D83, D84, D85, D86, D87, D88, D89, D90, D91, D92, D93, D94, D95, D96, D97, D98, D99, D100, D101, D102, D103, D104, D105, D106, D107, D108, D109, D110, D111, D112, D113, D114, D115, D116, D117, D118: B140S1F-7; D_SOD-123F
D119, D120, D121: LED; D_SOD-123F
D122, D123, D124: LED; LED_0603_1608Metric
J1: Prog_conn; DB_CONN
J2: Tag connect TC2030-CTX; TC2030-IDC-NL
J3: 53047-0460; Molex_PicoBlade_53048-0410_1x04_P1.25mm_Horizontal
J4: TYPE-C-31-M12_13; tyye_c_connector
J5: JST-4-pin
JP1: SolderJumper; SolderBridge
L1: 15nH; L_0402_1005Metric
L2, L3: 10uH; L_0603_1608Metric
L4: 4.7nH; L_0402_1005Metric
L5: 2.2nH; L_0402_1005Metric
L6: 60R@100MHz; L_0603_1608Metric
LED1, LED2, LED3, LED4, LED5, LED6, LED7, LED8, LED9, LED10, LED11, LED12, LED13, LED14, LED15, LED16, LED17, LED18, LED19, LED20, LED21, LED22, LED23, LED24, LED25, LED26, LED27, LED28, LED29, LED30, LED31, LED32, LED33, LED34, LED35, LED36, LED37, LED38, LED39, LED40, LED41, LED42, LED43, LED44, LED45, LED46, LED47, LED48, LED49, LED50, LED51, LED52, LED53, LED54, LED55, LED56, LED57, LED58, LED59, LED60, LED61, LED62, LED63, LED64, LED65, LED66, LED67, LED68, LED69, LED70, LED71, LED72, LED73, LED74, LED75, LED76, LED77, LED78, LED79, LED80, LED81, LED82, LED83, LED84, LED85, LED86, LED87, LED88, LED89, LED90, LED91, LED92, LED93, LED94, LED95, LED96, LED97, LED98, LED99, LED100, LED101, LED102, LED103, LED104, LED105, LED106, LED107, LED108, LED109, LED110, LED111, LED112, LED113, LED114, LED115, LED116, LED117, LED118: LED_ARGB; LED_WS2812B-2020_PLCC4_2.0x2.0mm
LED119, LED120, LED121: WS2812B; LED_WS2812B-2020_PLCC4_2.0x2.0mm
MX1, MX2, MX3, MX4, MX5, MX6, MX7, MX8, MX9, MX10, MX27, MX28, MX29, MX30: 1.00u; membrane
MX11, MX12, MX13, MX14, MX15, MX16, MX17, MX18, MX19, MX20, MX21, MX22, MX23, MX24, MX25, MX26, MX31, MX32, MX33, MX34, MX35, MX36, MX37, MX38, MX39, MX40, MX41, MX42, MX43, MX44, MX45, MX46, MX47, MX48, MX49, MX50, MX51, MX52, MX53, MX54, MX55, MX56, MX57, MX58, MX59, MX60, MX61, MX62, MX63, MX64, MX65, MX66, MX67, MX68, MX69, MX70, MX71, MX72, MX73, MX74, MX75, MX76, MX77, MX78, MX79, MX80, MX81, MX82, MX83, MX84, MX85, MX86, MX87, MX88, MX89, MX90, MX91, MX92, MX93, MX94, MX95, MX96, MX97, MX98, MX99, MX100, MX101, MX102, MX103, MX104, MX105, MX106, MX107, MX108, MX109, MX110, MX111, MX112, MX113, MX114, MX115, MX116, MX117, MX118: 1.00u; SW_Kailh_Choc_V1_THT
MX119, MX120, MX121: 1.00u; SW_Gateron_LowProfile_HotSwap_PTH
Q1, Q3: Q_NMOS; SOT-23-3
R1, R2, R3: 22E; R_0402_1005Metric
R4, R5, R6, R7, R10, R18, R19, R22, R24: 10k; R_0402_1005Metric
R8, R13, R17: R_US; R_0402_1005Metric
R9, R21, R23: 100; R_0402_1005Metric
R11, R12, R16: 5k1; R_0402_1005Metric
R14: 1k2; R_0402_1005Metric
R15: VAL; R_0402_1005Metric
S1: Open Hardware; OSHW-Logo
S2: BLE-symbol
S3: ZMK_logo
SW1: Reset Switch; RST_SW
TH1: 10k; R_0402_1005Metric
TP1: TestPoint; TestPoint_Pad_D1.5mm
U1: nRF52840-QIAA-R/nRF52833-QIAA-R; aqfn73
U2: TPD4E05U06DQAR; SOT-23-5
U3: BQ24074RGTR; USON-10
U4: BQ24074RGTR; QFN-16
Y1: 32.768kHz; SMD-2_crystal
Y2: 32MHz; SMD-4_crystal

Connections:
+5V: C18.1, C20.1, C23.1, C24.1, C25.1, C26.1, C27.1, C28.1, C29.1, C30.1, C31.1, C32.1, C33.1, C34.1, C35.1, C36.1, C37.1, C38.1, C39.1, C40.1, C41.1, C42.1, C43.1, C44.1, C45.1, C46.1, C47.1, C48.1, C49.1, C50.1, C51.1, C52.1, C53.1, C54.1, C55.1, C56.1, C57.1, C58.1, C59.1, C60.1, C61.1, C62.1, C63.1, C64.1, C65.1, C66.1, C67.1, C68.1, C69.1, C70.1, C71.1, C72.1, C73.1, C74.1, C75.1, C76.1, C77.1, C78.1, C79.1, C80.1, C81.1, C82.1, C83.1, C84.1, C85.1, C86.1, C87.1, C88.1, C89.1, C90.1, C91.1, C92.1, C93.1, C94.1, C95.1, C96.1, C97.1, C98.1, C99.1, C100.1, C101.1, C102.1, C103.1, C104.1, C105.1, C106.1, C107.1, C108.1, C109.1, C110.1, C111.1, C112.1, C113.1, C114.1, C115.1, C116.1, C117.1, C118.1, C119.1, C120.1, C121.1, C139.1, C141.1, J4.A4 (VBUS), J5.1, LED119.1 (VDD), LED120.1 (VDD), LED121.1 (VDD), R8.2, U1.AD2 (VBUS), U4.13 (IN)
/ANT_FEED: AE1.1 (A), L5.2
/CAPS_LED: R9.2, R23.2, U1.B13 (P0.03/AIN1)
/COL16: MX119.2 (B), U1.AC15 (P0.19)
/COL18: MX120.2 (B), U1.AC9 (P0.14)
/COL19: MX121.2 (B), U1.T2 (P0.11/TRACEDATA2)
/DB_SWDCLK: J1.1, J2.4, R1.1, R4.1
/DB_SWDIO: J1.6, J2.2, R2.1, R7.1
/DB_SWO: J1.2, J2.6, R3.1, R6.1
/LBAT_LED: R21.2, U1.K2 (P0.05/AIN3)
/USB and Power management/V_BATT: BT1.1 (+), C21.1, C142.1, R18.2, U3.2 (BAT_2), U3.3 (BAT_3), U4.2 (BAT_2), U4.3 (BAT_3)
/USB_D+: J4.A6 (D+), J4.B6 (D+), J5.3, U1.AD6 (D+), U2.1 (IO1), U2.4 (D2+)
/USB_D-: J4.A7 (D-), J4.B7 (D-), J5.2, U1.AD4 (D-), U2.2 (IO2), U2.5 (D2-)
/VBATT_nRF: C22.1, C143.1, R18.1, R19.2, U1.A12 (P0.02/AIN0)
/VDDH: J4.B4 (VBUS), R17.1, U1.Y2 (VDDH), U3.5 (EN2), U3.10 (OUT_10), U4.5 (EN2), U4.10 (OUT_10), U4.11 (OUT_11)
/VDD_nRF: C1.1, C4.2, C7.1, C10.1, C15.1, C122.1, C125.2, C128.1, C131.1, C136.1, J1.10, JP1.1 (A), L2.1, U1.A22 (VDD), U1.AD14 (VDD), U1.AD23 (VDD), U1.B1 (VDD), U1.W1 (VDD)
/VOL_A: J3.1, U1.P23 (P1.07)
/VOL_B: J3.3, U1.V23 (P1.03)
/VOL_C: J3.2, U1.T23 (P1.05)
/rgb-led_matrix/C1.2: LED11.1 (A), LED31.1 (A), LED52.1 (A), LED72.1 (A), LED88.1 (A), LED105.1 (A), LED106.1 (A)
/rgb-led_matrix/C1.3: LED32.1 (A), LED53.1 (A), LED73.1 (A), LED89.1 (A), LED107.1 (A)
/rgb-led_matrix/C1.4: LED1.1 (A), LED12.1 (A), LED33.1 (A), LED54.1 (A), LED74.1 (A)
/rgb-led_matrix/C1.5: LED2.1 (A), LED13.1 (A), LED34.1 (A), LED55.1 (A), LED75.1 (A), LED91.1 (A)
/rgb-led_matrix/C1.6: LED3.1 (A), LED14.1 (A), LED35.1 (A), LED56.1 (A), LED76.1 (A), LED92.1 (A)
/rgb-led_matrix/C1.7: LED4.1 (A), LED5.1 (A), LED6.1 (A), LED15.1 (A), LED36.1 (A), LED57.1 (A), LED77.1 (A), LED93.1 (A), LED108.1 (A)
/rgb-led_matrix/C1.8: LED37.1 (A), LED58.1 (A), LED78.1 (A), LED94.1 (A)
/rgb-led_matrix/C1.9: LED7.1 (A), LED16.1 (A), LED38.1 (A), LED59.1 (A), LED79.1 (A), LED95.1 (A)
/rgb-led_matrix/C1.10: LED8.1 (A), LED17.1 (A), LED39.1 (A), LED60.1 (A), LED80.1 (A), LED96.1 (A), LED109.1 (A)
/rgb-led_matrix/C1.11: LED9.1 (A), LED18.1 (A), LED40.1 (A), LED61.1 (A), LED81.1 (A), LED97.1 (A), LED110.1 (A)
/rgb-led_matrix/C1.12: LED10.1 (A), LED19.1 (A), LED41.1 (A), LED62.1 (A), LED82.1 (A), LED98.1 (A)
/rgb-led_matrix/C2.1: LED20.1 (A), LED42.1 (A), LED63.1 (A), LED83.1 (A), LED111.1 (A)
/rgb-led_matrix/C2.2: LED21.1 (A), LED43.1 (A), LED64.1 (A), LED84.1 (A), LED99.1 (A), LED112.1 (A)
/rgb-led_matrix/C2.3: LED22.1 (A), LED23.1 (A), LED44.1 (A), LED65.1 (A)
/rgb-led_matrix/C2.4: LED24.1 (A), LED45.1 (A), LED66.1 (A), LED113.1 (A)
/rgb-led_matrix/C2.5: LED25.1 (A), LED46.1 (A), LED67.1 (A), LED100.1 (A), LED114.1 (A)
/rgb-led_matrix/C2.6: LED26.1 (A), LED47.1 (A), LED68.1 (A), LED115.1 (A)
/rgb-led_matrix/C2.7: LED27.1 (A), LED48.1 (A), LED69.1 (A), LED85.1 (A), LED101.1 (A), LED116.1 (A)
/rgb-led_matrix/C2.8: LED28.1 (A), LED49.1 (A), LED70.1 (A), LED86.1 (A)
/rgb-led_matrix/C2.9: LED29.1 (A), LED50.1 (A), LED71.1 (A), LED87.1 (A), LED117.1 (A)
/rgb-led_matrix/C2.10: LED30.1 (A), LED51.1 (A), LED104.1 (A), LED118.1 (A)
/rgb-led_matrix/S1.1: LED1.2 (RK), LED2.2 (RK), LED3.2 (RK), LED4.2 (RK), LED5.2 (RK), LED6.2 (RK), LED7.2 (RK), LED8.2 (RK), LED9.2 (RK), LED10.2 (RK), LED11.2 (RK), LED12.2 (RK), LED13.2 (RK), LED14.2 (RK), LED15.2 (RK), LED16.2 (RK), LED17.2 (RK), LED18.2 (RK), LED19.2 (RK)
/rgb-led_matrix/S1.2: LED1.3 (GK), LED2.3 (GK), LED3.3 (GK), LED4.3 (GK), LED5.3 (GK), LED6.3 (GK), LED7.3 (GK), LED8.3 (GK), LED9.3 (GK), LED10.3 (GK), LED11.3 (GK), LED12.3 (GK), LED13.3 (GK), LED14.3 (GK), LED15.3 (GK), LED16.3 (GK), LED17.3 (GK), LED18.3 (GK), LED19.3 (GK)
/rgb-led_matrix/S1.3: LED1.4 (BK), LED2.4 (BK), LED3.4 (BK), LED4.4 (BK), LED5.4 (BK), LED6.4 (BK), LED7.4 (BK), LED8.4 (BK), LED9.4 (BK), LED10.4 (BK), LED11.4 (BK), LED12.4 (BK), LED13.4 (BK), LED14.4 (BK), LED15.4 (BK), LED16.4 (BK), LED17.4 (BK), LED18.4 (BK), LED19.4 (BK)
/rgb-led_matrix/S1.4: LED31.2 (RK), LED32.2 (RK), LED33.2 (RK), LED34.2 (RK), LED35.2 (RK), LED36.2 (RK), LED37.2 (RK), LED38.2 (RK), LED39.2 (RK), LED40.2 (RK), LED41.2 (RK), LED52.2 (RK), LED53.2 (RK), LED54.2 (RK), LED55.2 (RK), LED56.2 (RK), LED57.2 (RK), LED58.2 (RK), LED59.2 (RK), LED60.2 (RK), LED61.2 (RK), LED62.2 (RK)
/rgb-led_matrix/S1.5: LED31.3 (GK), LED32.3 (GK), LED33.3 (GK), LED34.3 (GK), LED35.3 (GK), LED36.3 (GK), LED37.3 (GK), LED38.3 (GK), LED39.3 (GK), LED40.3 (GK), LED41.3 (GK), LED52.3 (GK), LED53.3 (GK), LED54.3 (GK), LED55.3 (GK), LED56.3 (GK), LED57.3 (GK), LED58.3 (GK), LED59.3 (GK), LED60.3 (GK), LED61.3 (GK), LED62.3 (GK)
/rgb-led_matrix/S1.6: LED31.4 (BK), LED32.4 (BK), LED33.4 (BK), LED34.4 (BK), LED35.4 (BK), LED36.4 (BK), LED37.4 (BK), LED38.4 (BK), LED39.4 (BK), LED40.4 (BK), LED41.4 (BK), LED52.4 (BK), LED53.4 (BK), LED54.4 (BK), LED55.4 (BK), LED56.4 (BK), LED57.4 (BK), LED58.4 (BK), LED59.4 (BK), LED60.4 (BK), LED61.4 (BK), LED62.4 (BK)
/rgb-led_matrix/S1.7: LED72.2 (RK), LED73.2 (RK), LED74.2 (RK), LED75.2 (RK), LED76.2 (RK), LED77.2 (RK), LED78.2 (RK), LED79.2 (RK), LED80.2 (RK), LED81.2 (RK), LED82.2 (RK), LED88.2 (RK), LED89.2 (RK), LED90.2 (RK), LED91.2 (RK), LED92.2 (RK), LED93.2 (RK), LED94.2 (RK), LED95.2 (RK), LED96.2 (RK), LED97.2 (RK), LED98.2 (RK)
/rgb-led_matrix/S1.8: LED72.3 (GK), LED73.3 (GK), LED74.3 (GK), LED75.3 (GK), LED76.3 (GK), LED77.3 (GK), LED78.3 (GK), LED79.3 (GK), LED80.3 (GK), LED81.3 (GK), LED82.3 (GK), LED88.3 (GK), LED89.3 (GK), LED90.3 (GK), LED91.3 (GK), LED92.3 (GK), LED93.3 (GK), LED94.3 (GK), LED95.3 (GK), LED96.3 (GK), LED97.3 (GK), LED98.3 (GK)
/rgb-led_matrix/S1.9: LED72.4 (BK), LED73.4 (BK), LED74.4 (BK), LED75.4 (BK), LED76.4 (BK), LED77.4 (BK), LED78.4 (BK), LED79.4 (BK), LED80.4 (BK), LED81.4 (BK), LED82.4 (BK), LED88.4 (BK), LED89.4 (BK), LED90.4 (BK), LED91.4 (BK), LED92.4 (BK), LED93.4 (BK), LED94.4 (BK), LED95.4 (BK), LED96.4 (BK), LED97.4 (BK), LED98.4 (BK)
/rgb-led_matrix/S1.10: LED105.2 (RK), LED106.2 (RK), LED107.2 (RK), LED108.2 (RK), LED109.2 (RK), LED110.2 (RK)
/rgb-led_matrix/S1.11: LED105.3 (GK), LED106.3 (GK), LED107.3 (GK), LED108.3 (GK), LED109.3 (GK), LED110.3 (GK)
/rgb-led_matrix/S1.12: LED105.4 (BK), LED106.4 (BK), LED107.4 (BK), LED108.4 (BK), LED109.4 (BK), LED110.4 (BK)
/rgb-led_matrix/S2.1: LED20.2 (RK), LED21.2 (RK), LED22.2 (RK), LED23.2 (RK), LED24.2 (RK), LED25.2 (RK), LED26.2 (RK), LED27.2 (RK), LED28.2 (RK), LED29.2 (RK), LED30.2 (RK)
/rgb-led_matrix/S2.2: LED20.3 (GK), LED21.3 (GK), LED22.3 (GK), LED23.3 (GK), LED24.3 (GK), LED25.3 (GK), LED26.3 (GK), LED27.3 (GK), LED28.3 (GK), LED29.3 (GK)
/rgb-led_matrix/S2.3: LED20.4 (BK), LED21.4 (BK), LED22.4 (BK), LED23.4 (BK), LED24.4 (BK), LED25.4 (BK), LED26.4 (BK), LED27.4 (BK), LED28.4 (BK), LED29.4 (BK)
/rgb-led_matrix/S2.4: LED42.2 (RK), LED43.2 (RK), LED44.2 (RK), LED45.2 (RK), LED46.2 (RK), LED47.2 (RK), LED48.2 (RK), LED49.2 (RK), LED50.2 (RK), LED51.2 (RK), LED63.2 (RK), LED64.2 (RK), LED65.2 (RK), LED66.2 (RK), LED67.2 (RK), LED68.2 (RK), LED69.2 (RK), LED70.2 (RK), LED71.2 (RK), LED104.2 (RK)
/rgb-led_matrix/S2.5: LED42.3 (GK), LED43.3 (GK), LED44.3 (GK), LED45.3 (GK), LED46.3 (GK), LED47.3 (GK), LED48.3 (GK), LED49.3 (GK), LED50.3 (GK), LED51.3 (GK), LED63.3 (GK), LED64.3 (GK), LED65.3 (GK), LED66.3 (GK), LED67.3 (GK), LED68.3 (GK), LED69.3 (GK), LED70.3 (GK), LED71.3 (GK), LED104.3 (GK)
/rgb-led_matrix/S2.6: LED42.4 (BK), LED43.4 (BK), LED44.4 (BK), LED45.4 (BK), LED46.4 (BK), LED47.4 (BK), LED48.4 (BK), LED49.4 (BK), LED50.4 (BK), LED51.4 (BK), LED63.4 (BK), LED64.4 (BK), LED65.4 (BK), LED66.4 (BK), LED67.4 (BK), LED68.4 (BK), LED69.4 (BK), LED70.4 (BK), LED71.4 (BK), LED104.4 (BK)
/rgb-led_matrix/S2.7: LED83.2 (RK), LED84.2 (RK), LED85.2 (RK), LED86.2 (RK), LED87.2 (RK), LED99.2 (RK), LED100.2 (RK), LED101.2 (RK), LED102.2 (RK), LED103.2 (RK), LED118.2 (RK)
/rgb-led_matrix/S2.8: LED83.3 (GK), LED84.3 (GK), LED85.3 (GK), LED86.3 (GK), LED87.3 (GK), LED99.3 (GK), LED100.3 (GK), LED101.3 (GK), LED102.3 (GK), LED103.3 (GK), LED118.3 (GK)
/rgb-led_matrix/S2.9: LED83.4 (BK), LED84.4 (BK), LED85.4 (BK), LED86.4 (BK), LED87.4 (BK), LED99.4 (BK), LED100.4 (BK), LED101.4 (BK), LED102.4 (BK), LED103.4 (BK), LED118.4 (BK)
/rgb-led_matrix/S2.10: LED111.2 (RK), LED112.2 (RK), LED113.2 (RK), LED114.2 (RK), LED115.2 (RK), LED116.2 (RK), LED117.2 (RK)
/rgb-led_matrix/S2.11: LED111.3 (GK), LED112.3 (GK), LED113.3 (GK), LED114.3 (GK), LED115.3 (GK), LED116.3 (GK), LED117.3 (GK)
/rgb-led_matrix/S2.12: LED111.4 (BK), LED112.4 (BK), LED113.4 (BK), LED114.4 (BK), LED115.4 (BK), LED116.4 (BK), LED117.4 (BK)
/switch_matrix/COL1: MX11.2 (B), MX31.2 (B), MX52.2 (B), MX73.2 (B), MX89.2 (B), MX106.2 (B), MX107.2 (B)
/switch_matrix/COL2: MX32.2 (B), MX53.2 (B), MX74.2 (B), MX90.2 (B), MX108.2 (B)
/switch_matrix/COL3: MX12.2 (B), MX33.2 (B), MX54.2 (B), MX75.2 (B), MX91.2 (B)
/switch_matrix/COL4: MX13.2 (B), MX34.2 (B), MX55.2 (B), MX76.2 (B), MX92.2 (B)
/switch_matrix/COL5: MX15.2 (B), MX35.2 (B), MX56.2 (B), MX77.2 (B), MX93.2 (B)
/switch_matrix/COL6: MX16.2 (B), MX36.2 (B), MX57.2 (B), MX78.2 (B), MX94.2 (B), MX109.2 (B)
/switch_matrix/COL7: MX37.2 (B), MX58.2 (B), MX79.2 (B), MX95.2 (B)
/switch_matrix/COL8: MX14.2 (B), MX38.2 (B), MX59.2 (B), MX80.2 (B), MX96.2 (B)
/switch_matrix/COL9: MX17.2 (B), MX39.2 (B), MX60.2 (B), MX81.2 (B), MX97.2 (B), MX110.2 (B)
/switch_matrix/COL10: MX18.2 (B), MX40.2 (B), MX61.2 (B), MX82.2 (B), MX98.2 (B), MX111.2 (B)
/switch_matrix/COL11: MX19.2 (B), MX41.2 (B), MX62.2 (B), MX83.2 (B), MX99.2 (B)
/switch_matrix/COL12: MX20.2 (B), MX42.2 (B), MX63.2 (B), MX84.2 (B), MX112.2 (B)
/switch_matrix/COL13: MX21.2 (B), MX43.2 (B), MX64.2 (B), MX85.2 (B), MX100.2 (B), MX113.2 (B)
/switch_matrix/COL14: MX22.2 (B), MX23.2 (B), MX44.2 (B), MX65.2 (B)
/switch_matrix/COL15: MX24.2 (B), MX45.2 (B), MX66.2 (B), MX114.2 (B)
/switch_matrix/COL16: MX25.2 (B), MX46.2 (B), MX67.2 (B), MX101.2 (B), MX115.2 (B)
/switch_matrix/COL17: MX26.2 (B), MX47.2 (B), MX68.2 (B), MX116.2 (B)
/switch_matrix/COL18: MX48.2 (B), MX69.2 (B), MX86.2 (B), MX102.2 (B), MX117.2 (B)
/switch_matrix/COL19: MX49.2 (B), MX70.2 (B), MX87.2 (B), MX103.2 (B)
/switch_matrix/COL20: MX50.2 (B), MX71.2 (B), MX88.2 (B), MX104.2 (B), MX118.2 (B)
/switch_matrix/COL21: MX51.2 (B), MX72.2 (B), MX105.2 (B)
/switch_matrix/K_RIGHT/DOUT: LED119.2 (DOUT), LED120.4 (DIN)
/switch_matrix/K_np0/DOUT: LED120.2 (DOUT), LED121.4 (DIN)
/switch_matrix/ROW0: D11.1 (K), D12.1 (K), D13.1 (K), D14.1 (K), D15.1 (K), D16.1 (K), D17.1 (K), D18.1 (K), D19.1 (K), D20.1 (K), D21.1 (K), D22.1 (K), D23.1 (K), D24.1 (K), D25.1 (K), D26.1 (K)
/switch_matrix/ROW1: D31.1 (K), D32.1 (K), D33.1 (K), D34.1 (K), D35.1 (K), D36.1 (K), D37.1 (K), D38.1 (K), D39.1 (K), D40.1 (K), D41.1 (K), D42.1 (K), D43.1 (K), D44.1 (K), D45.1 (K), D46.1 (K), D47.1 (K), D48.1 (K), D49.1 (K), D50.1 (K), D51.1 (K)
/switch_matrix/ROW2: D52.1 (K), D53.1 (K), D54.1 (K), D55.1 (K), D56.1 (K), D57.1 (K), D58.1 (K), D59.1 (K), D60.1 (K), D61.1 (K), D62.1 (K), D63.1 (K), D64.1 (K), D65.1 (K), D66.1 (K), D67.1 (K), D68.1 (K), D69.1 (K), D70.1 (K), D71.1 (K), D72.1 (K)
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
